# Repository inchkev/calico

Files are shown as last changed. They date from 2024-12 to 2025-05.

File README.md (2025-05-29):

# calico

calico is a 54 key (6x4+3 split) column-staggered choc-spaced split ergonomic keyboard with freehanded traces and diode sprinkles

* pro micro based
* reversible pcb
* choc v1 hotswap only

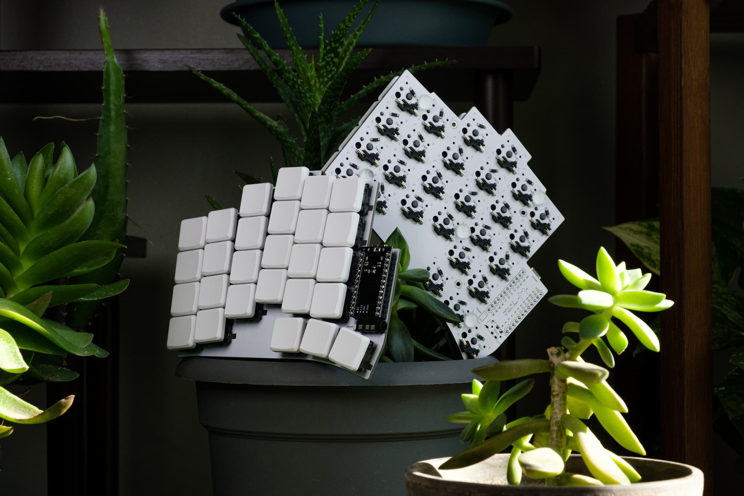
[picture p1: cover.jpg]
holding calico


## board

### v0.2

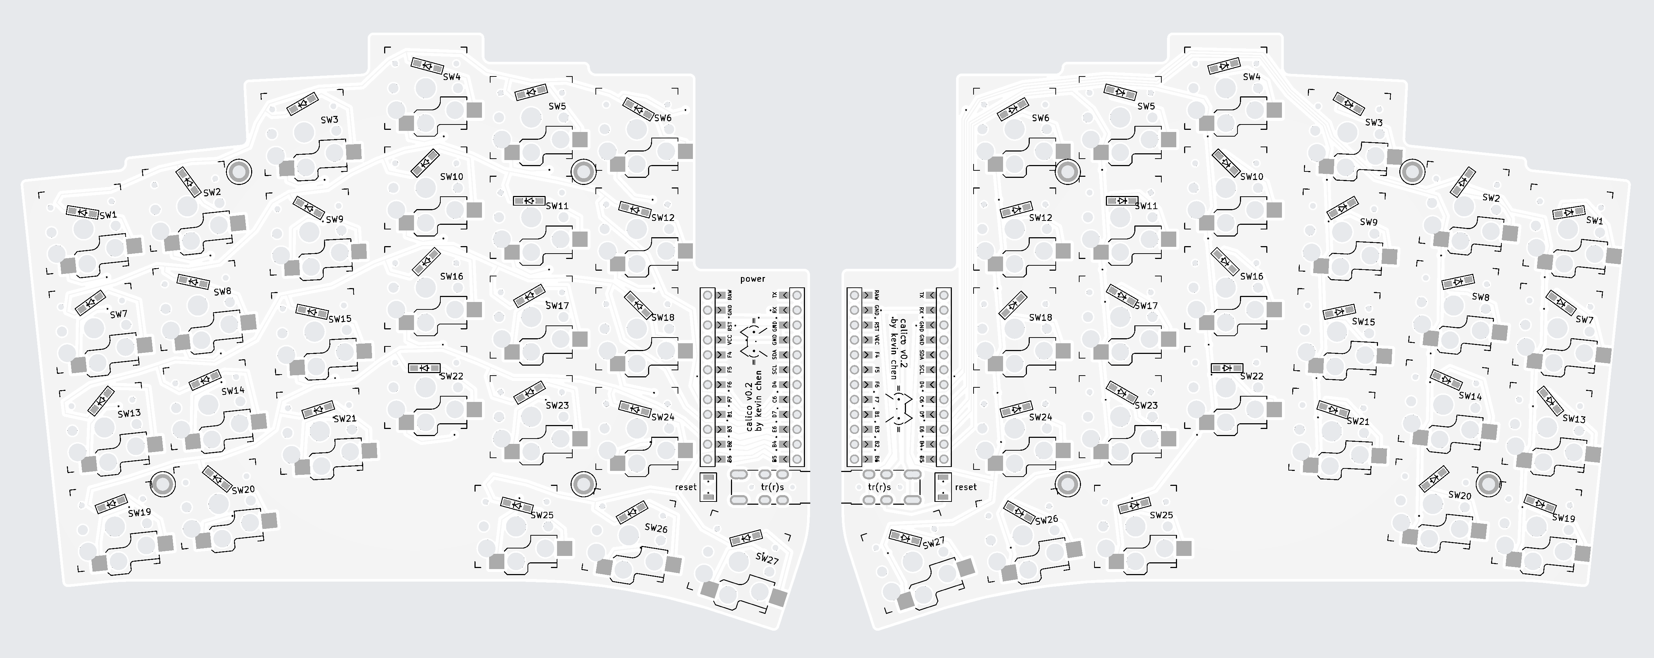
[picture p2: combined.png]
combined view


changes from v0.1

* brought trrs jack all the way to the edge
* brought pro micro down a bit, close gap with trrs
* modify footprints for reset and trrs
* use different footprint for the pro micro

## to build calico, you'll need:

* 2x calico v0.2 pcbs
* 2x pro micro compatible boards
* 54x choc v1 switches
* 54x choc 1u keycaps (I used MBK profile)
* 54x Kailh choc hotswap sockets
* 54x SOD-123 diodes (I used 1N4148W)
* 2x TRRS PJ-320A jacks
* 1x TRRS cable
* 2x tact switch (optional, just carry a paperclip)
* at least 8x rubber feet (I used 10)
* 1x usb-c cable

I'd also recommend socketing your pro micros:

* 4x BBL-112-T-E Samtec ([mouser](https://www.mouser.com/ProductDetail/Samtec/BBL-112-T-E?qs=FESYatJ8odKicQFiFw2tKA%3D%3D), [digikey](https://www.digikey.com/en/products/detail/samtec-inc/BBL-112-T-E/1099406))
* 4x 315-43-112-41-003000 Mill-Max ([mouser](https://www.mouser.com/ProductDetail/Mill-Max/315-43-112-41-003000?qs=s8Nb1z4Wn%2FRfWrVqQ0TOuQ%3D%3D), [digikey](https://www.digikey.com/en/products/detail/mill-max-manufacturing-corp/315-43-112-41-003000/4455232))

## calico was inspired by

* [Lily58 by kata0510](https://github.com/kata0510/Lily58)
* [Peter Blasser's Ciat-Lonbarde PCBs](https://www.ciat-lonbarde.net/)
* [bugs by jimmerricks](https://github.com/jimmerricks/bugs)
* [Swoop MX by jimmerricks](https://github.com/jimmerricks/swoop)
* [Sweep Half Swept by David Barr](https://github.com/davidphilipbarr/Sweep)
* [keyboards by mindhatch](https://github.com/mindhatch/keyboards)
* [Sofle by Joseph Adamčík](https://josefadamcik.github.io/SofleKeyboard/)
* [TOTEM by GEIGEIGEIST](https://github.com/GEIGEIGEIST/TOTEM)

### and designed with the use of

* [ergogen](https://github.com/ergogen/ergogen)
* [kicad-kbplacer](https://github.com/adamws/kicad-kbplacer/tree/master)

### and licensed under

[CERN-OHL-W-2.0](https://spdx.org/licenses/CERN-OHL-W-2.0.html) overall. calico uses footprints, modified and unmodified, under different licenses. see [ATTRIBUTIONS.md](ATTRIBUTIONS.md).

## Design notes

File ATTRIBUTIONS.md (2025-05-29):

### `calico.pretty/libraries/`

#### `Choc_Hotswap.kicad_mod`, `Choc_Hotwap_w_diode.kicad_mod`

By [Gareth Chen](https://github.com/50an6xy06r6n) (c) 2021, licensed under [MIT](https://opensource.org/license/mit), from [50an6xy06r6n/keyboard\_reversible.pretty](https://github.com/50an6xy06r6n/keyboard_reversible.pretty). See [libraries/LICENSE-MIT](libraries/LICENSE-MIT).

#### `Kailh_socket_PG1350_reversible.kicad_mod`, `Kailh_socket_PG1350_optional_reversible`

By [Dale Price](https://github.com/daprice), licensed under [CC BY-SA 4.0](https://creativecommons.org/licenses/by-sa/4.0/), from [daprice/keyswitches.pretty](https://github.com/daprice/keyswitches.pretty).

#### `D_SMD_TH.kicad_mod`, `D3_SMD.kicad_mod`, `Reset.kicad_mod`, `TRRS-3pin.kicad_mod`, `ProMicro_jumpers.kicad_mod` 

By [Jim Merricks White](https://github.com/jimmerricks) (c) 2021, from [jimmerricks/swoop](https://github.com/jimmerricks/swoop/tree/main/libraries/swoop.pretty). See [libraries/LICENSE-SHL](libraries/LICENSE-SHL).

#### `D3_SMD_modified.kicad_mod`, `Reset_modified.kicad_mod`, `TRRS-3pin_modified.kicad_mod`

Modified footprints by [Kevin Chen](https://github.com/inchkev/), licensed under [Apache-2.0 WITH SHL-2.1](https://solderpad.org/licenses/SHL-2.1/). Modified with slight changes to only the silkscreen layers.
See [libraries/LICENSE-SHL](libraries/LICENSE-SHL).

Original footprints by [Jim Merricks White](https://github.com/jimmerricks) (c) 2021, licensed under Apache-2.0 WITH SHL-2.1, from [jimmerricks/swoop](https://github.com/jimmerricks/swoop/tree/main/libraries/swoop.pretty).

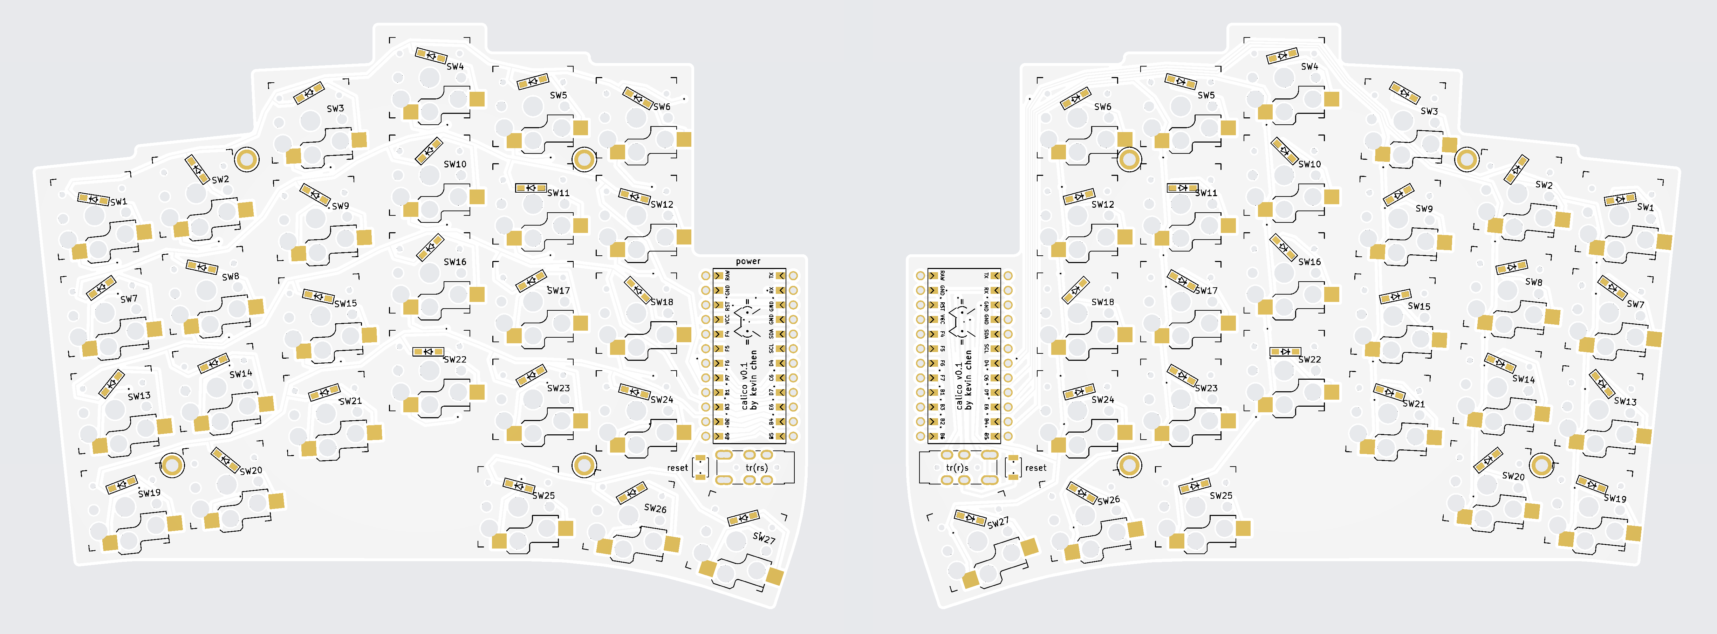
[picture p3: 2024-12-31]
img/combined-0.1.png

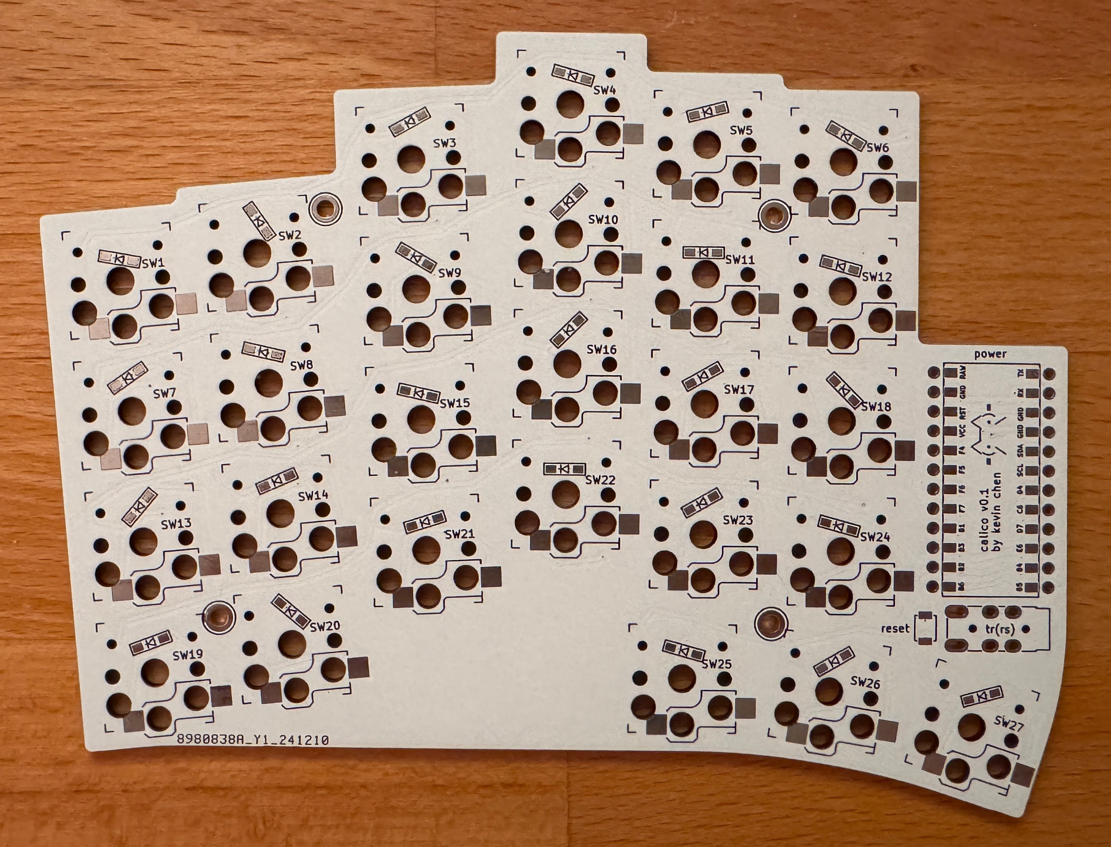
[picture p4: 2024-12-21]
img/photo-0.1.jpg

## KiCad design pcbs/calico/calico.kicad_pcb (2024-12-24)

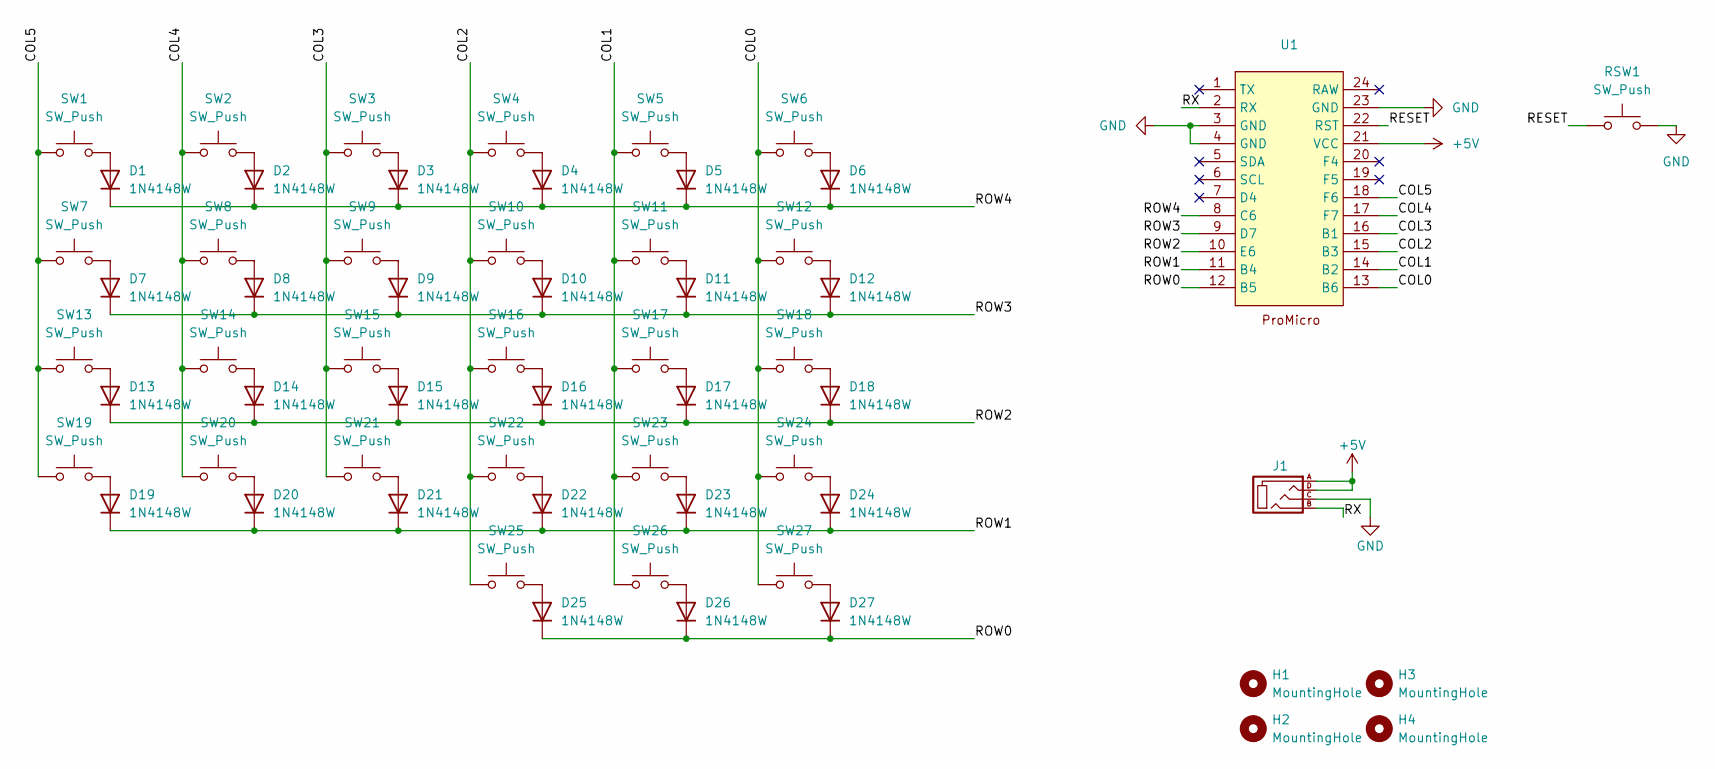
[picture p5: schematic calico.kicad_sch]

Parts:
D1, D2, D3, D4, D5, D6, D7, D8, D9, D10, D11, D12, D13, D14, D15, D16, D17, D18, D19, D20, D21, D22, D23, D24, D25, D26, D27: 1N4148W; D3_SMD_modified
H1, H2, H3, H4: MountingHole; MountingHole_2.2mm_M2_ISO7380_Pad_TopBottom
J1: MJ-4PP-9-kbd-corne-light-rescue; TRRS-3pin_modified
RSW1: SW_Push; Reset_modified
SW1, SW2, SW3, SW4, SW5, SW6, SW7, SW8, SW9, SW10, SW11, SW12, SW13, SW14, SW15, SW16, SW17, SW18, SW19, SW20, SW21, SW22, SW23, SW24, SW25, SW26, SW27: SW_Push; Kailh_socket_PG1350_reversible
U1: ProMicro_jumpers

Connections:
+5V: J1.A, J1.D, U1.21 (VCC)
/COL0: SW6.1, SW12.1, SW18.1, SW24.1, SW27.1, U1.13 (B6)
/COL1: SW5.1, SW11.1, SW17.1, SW23.1, SW26.1, U1.14 (B2)
/COL2: SW4.1, SW10.1, SW16.1, SW22.1, SW25.1, U1.15 (B3)
/COL3: SW3.1, SW9.1, SW15.1, SW21.1, U1.16 (B1)
/COL4: SW2.1, SW8.1, SW14.1, SW20.1, U1.17 (F7)
/COL5: SW1.1, SW7.1, SW13.1, SW19.1, U1.18 (F6)
/RESET: RSW1.1, U1.22 (RST)
/ROW0: D25.1 (K), D26.1 (K), D27.1 (K), U1.12 (B5)
/ROW1: D19.1 (K), D20.1 (K), D21.1 (K), D22.1 (K), D23.1 (K), D24.1 (K), U1.11 (B4)
/ROW2: D13.1 (K), D14.1 (K), D15.1 (K), D16.1 (K), D17.1 (K), D18.1 (K), U1.10 (E6)
/ROW3: D7.1 (K), D8.1 (K), D9.1 (K), D10.1 (K), D11.1 (K), D12.1 (K), U1.9 (D7)
/ROW4: D1.1 (K), D2.1 (K), D3.1 (K), D4.1 (K), D5.1 (K), D6.1 (K), U1.8 (C6)
/RX: J1.B, U1.2 (RX)
GND: J1.C, RSW1.2, U1.3 (GND), U1.4 (GND), U1.23 (GND)
unnamed: D1.2 (A), SW1.2
unnamed: D2.2 (A), SW2.2
unnamed: D3.2 (A), SW3.2
unnamed: D4.2 (A), SW4.2
unnamed: D5.2 (A), SW5.2
unnamed: D6.2 (A), SW6.2
unnamed: D7.2 (A), SW7.2
unnamed: D8.2 (A), SW8.2
unnamed: D9.2 (A), SW9.2
unnamed: D10.2 (A), SW10.2
unnamed: D11.2 (A), SW11.2
unnamed: D12.2 (A), SW12.2
unnamed: D13.2 (A), SW13.2
unnamed: D14.2 (A), SW14.2
unnamed: D15.2 (A), SW15.2
unnamed: D16.2 (A), SW16.2
unnamed: D17.2 (A), SW17.2
unnamed: D18.2 (A), SW18.2
unnamed: D19.2 (A), SW19.2
unnamed: D20.2 (A), SW20.2
unnamed: D21.2 (A), SW21.2
unnamed: D22.2 (A), SW22.2
unnamed: D23.2 (A), SW23.2
unnamed: D24.2 (A), SW24.2
unnamed: D25.2 (A), SW25.2
unnamed: D26.2 (A), SW26.2
unnamed: D27.2 (A), SW27.2

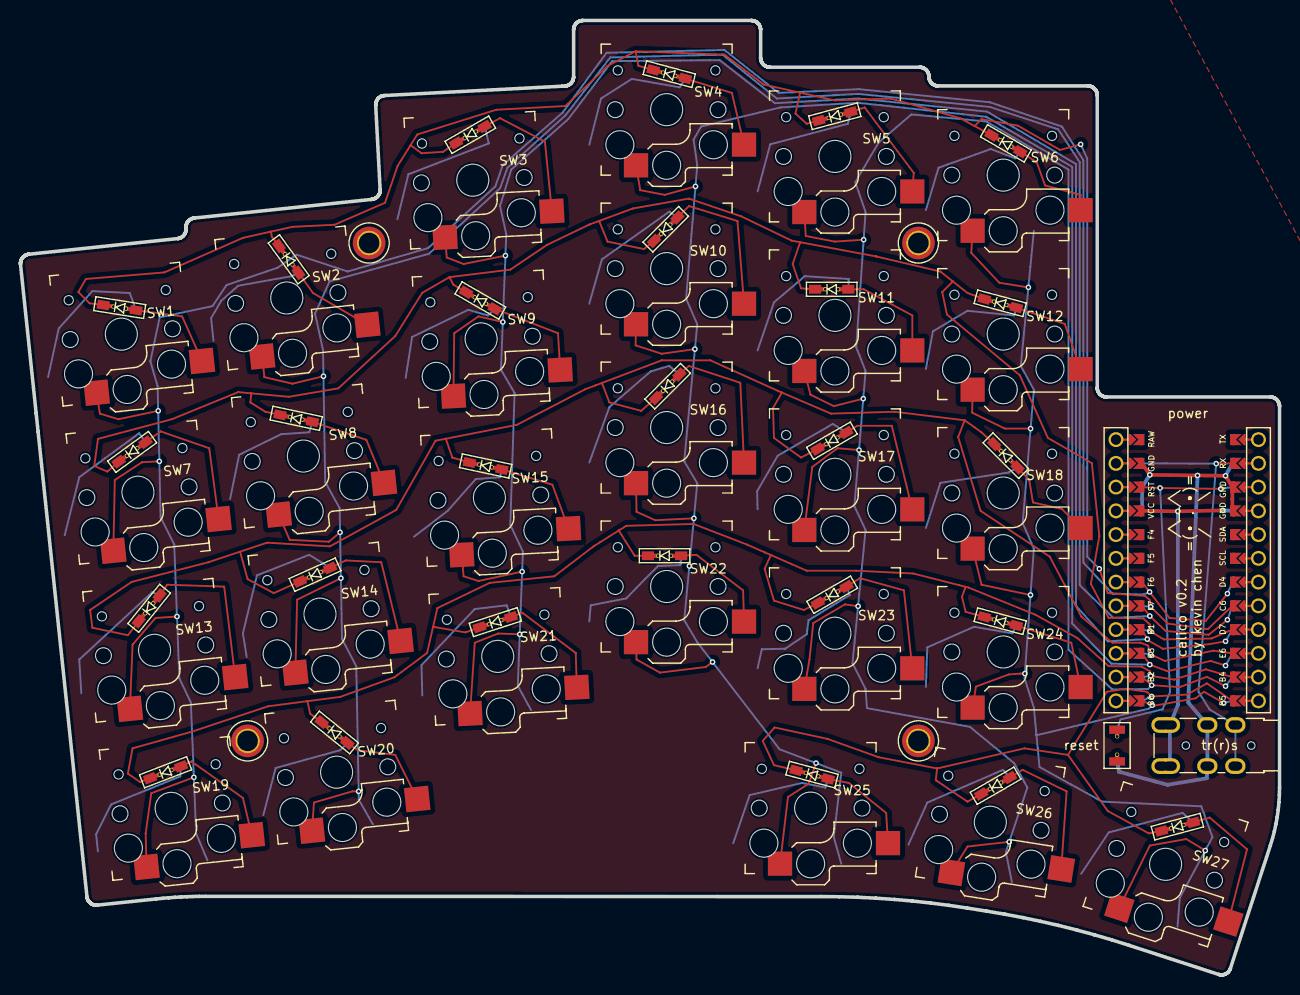
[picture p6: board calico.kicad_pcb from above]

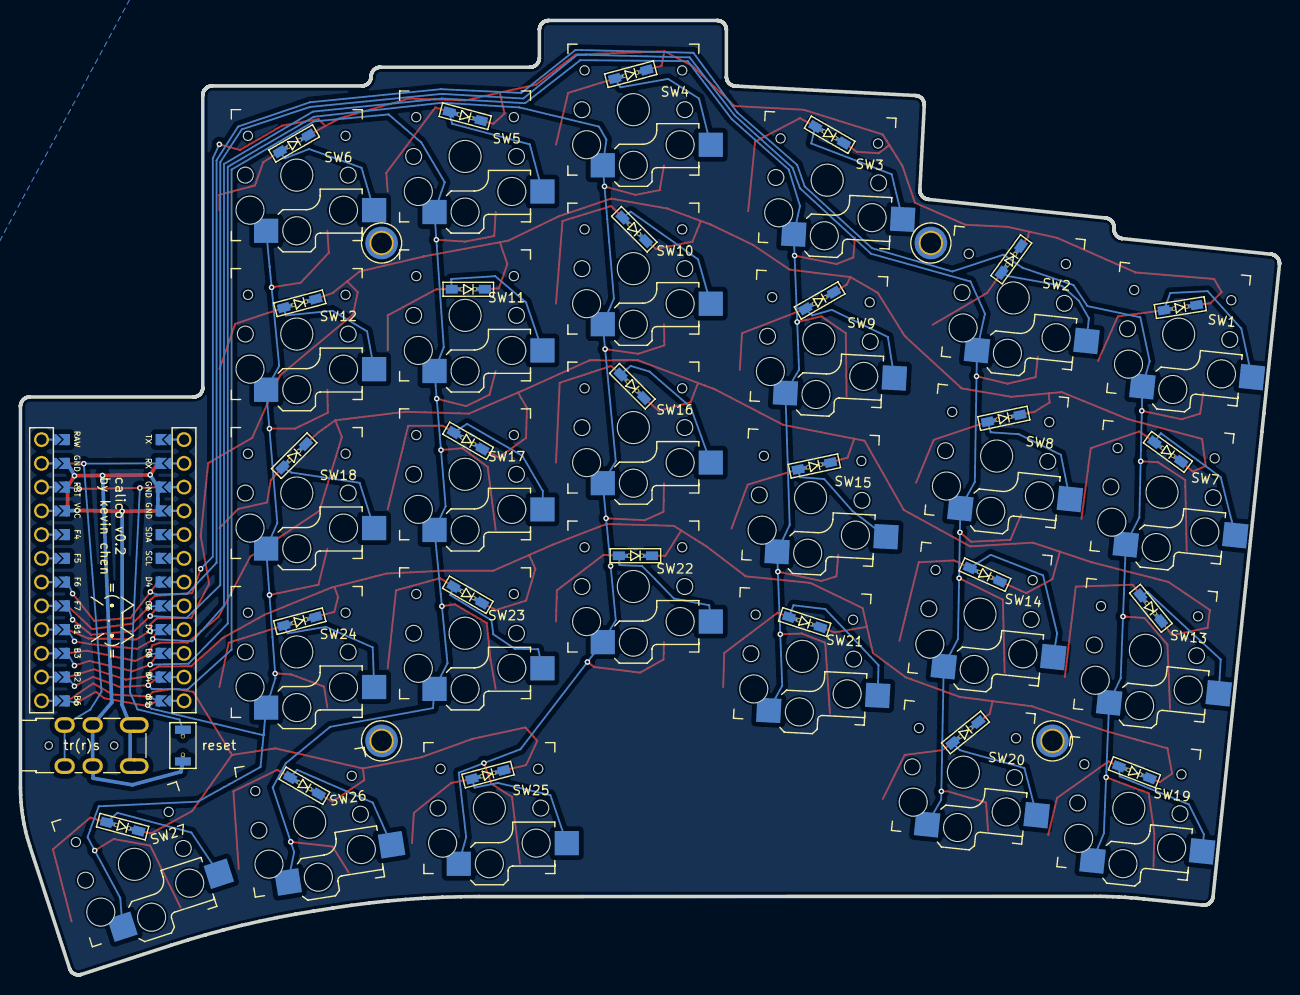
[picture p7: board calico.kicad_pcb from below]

Board: 2 copper layers, 134.7 x 102.1 mm, 61 parts (27 on the bottom side), 42 nets.

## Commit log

2024-12-19 v0.2 initial
    [calico.kicad_pcb, calico.kicad_sch]
2024-12-21 v0.2 updated
    [calico.kicad_pcb]
2024-12-24 Add licenses
    [calico.kicad_pcb]
2024-12-31 edit trace color
